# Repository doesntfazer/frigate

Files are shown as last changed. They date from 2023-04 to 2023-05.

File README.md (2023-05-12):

# frigate
32/34 Key Keyboard, integrated rp2040

# Frigate V1 is not working. V2 is the final version of this keyboard.
Frigate V2 final are not the same as the Early adopter boards. This one has all of the silscreens, and it is also wired to support i2c and SPI versions of the cirque.
The early adopters version only supports SPI.

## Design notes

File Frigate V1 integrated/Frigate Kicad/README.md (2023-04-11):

# frigate
32 Key Keyboard, integrated rp2040 With Hot Swap sockets

Order at your own risk. Keyboards have not yet been tested. (They have been ordered, and will be tested as soon as I get them)

frigate

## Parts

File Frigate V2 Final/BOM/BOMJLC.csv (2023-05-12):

Comment | Designator | Footprint | LCSC Part #
1N4148W | D1, D2, D3, D4, D5, D6, D7, D8, D9, D10, D11, D12, D13, D14, D15, D16, D17, D18, D19, D20, D21, D22, D23, D24, D25, D26, D27, D28, D29, D30, D31, D32, D33, D34 | D_SOD-123 | C25133
75 0402 | R1 | R_0402_1005Metric | C25798
LED_0603 | U2 | LED_0603 | C2286
SW_PUSH | SW1, SW2, SW3, SW4, SW5, SW6, SW7, SW8, SW9, SW10, SW11, SW12, SW13, SW14, SW15, SW16, SW17, SW18, SW19, SW20, SW21, SW22, SW23, SW24, SW25, SW26, SW27, SW28, SW29, SW30, SW31, SW32, SW33, SW34 | Kailh_socket_MX_4fab | C5156480

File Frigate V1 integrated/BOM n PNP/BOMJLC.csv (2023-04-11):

Comment | Designator | Footprint | LCSC Part #
10uf 0402 | C1, C2, C17 | C_0402_1005Metric | no_part_number
0.1uf 0402 | C3 | C_0402_1005Metric | no_part_number
100nf 0402 | C4, C5, C6, C7, C8, C9, C10, C11, C12, C15 | C_0402_1005Metric | no_part_number
2.2uF 0402 | C13, C16 | C_0402_1005Metric | no_part_number
1uf 0402 | C14 | C_0402_1005Metric | no_part_number
22pf 0402 | C18, C19 | C_0402_1005Metric | no_part_number
1N4148W | D1, D2, D3, D4, D5, D6, D7, D8, D9, D10, D11, D12, D13, D14, D15, D16, D17, D18, D19, D20, D21, D22, D23, D24, D25, D26, D27, D28, D29, D30, D31, D32 | D_SOD-123 | C2892570
1N4002W | D33 | D_SOD-123 | C169542
0805L050WR | F1 | Fuse_0805_2012Metric | C207022
FerriteBead 0402 | FB1 | R_0402_1005Metric | no_part_number
W25Q16JVUXIQ | FLASH1 | R_0402_1005Metric | C2843335
GP23 LED_0402 | GP23_LED1 | LED_0402_1005Metric | no_part_number
1K 0402 | GPIO24_RESISTOR1 | R_0402_1005Metric | no_part_number
LED_0402 | GPIO25_LED1 | LED_0402_1005Metric | no_part_number
470 0402 | GPIO25_RESISTOR1 | R_0402_1005Metric | no_part_number
Button | J3 | SW_Push_SPST_NO_Alps_SKRK | no_part_number
NetTie_2 | NT1 | NetTie-2_SMD_Pad0.5mm | no_part_number
SI2301B | Q1 | SOT-23 | no_part_number
5.1K 0402 | R1, R3 | R_0402_1005Metric | no_part_number
5.6K 0402 | R2 | R_0402_1005Metric | no_part_number
100K 0402 | R4 | R_0402_1005Metric | no_part_number
220 0402 | R5 | R_0402_1005Metric | no_part_number
10K 0402 | R6, R9 | R_0402_1005Metric | no_part_number
200 0603 | R7 | R_0402_1005Metric | no_part_number
1 0402 | R8 | R_0402_1005Metric | no_part_number
27r 0402 resistor | R10, R11 | R_0402_1005Metric | no_part_number
1K 0402 | R12, R13 | R_0402_1005Metric | no_part_number
TSA343G00-250J2 | RSW1 | SW_Push_SPST_NO_Alps_SKRK | C354946
SW_PUSH | SW1-SW32 | CherryMX_Hotswap-3d-smd | C5156480
TestPoint | TP1, TP2, TP3 | CustomTestPoint | no_part_number
SOT-23-5 5.5V 3.3V 500mA | U2 | SOT-23-5 | C404027
RP2040 | U3 | RP2040-QFN-56 | C2040
TYPE-C-31-M-12 | USB1 | HRO-TYPE-C-31-M-12 | C165948
3225_4P 12MHz | Y1 | Crystal_SMD_3225-4Pin_3.2x2.5mm | C295522

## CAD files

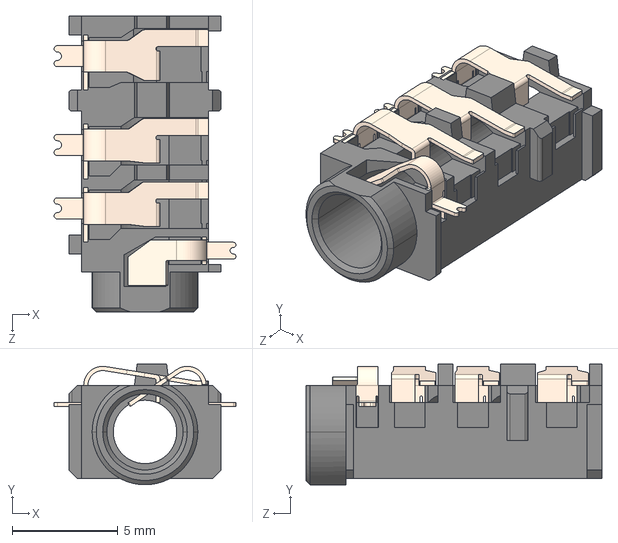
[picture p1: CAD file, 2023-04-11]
Frigate V1 integrated/components/Keebio-Parts.pretty-master/3dmodels/CUI_SJ-43614-SMT-TR.step
8.60 x 5.70 x 14.0 mm

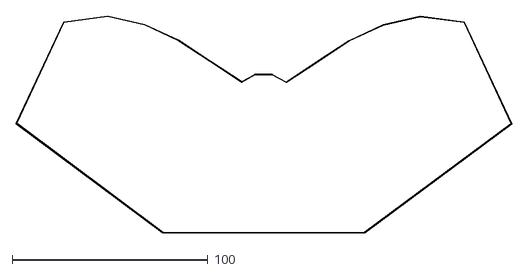
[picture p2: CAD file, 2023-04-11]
Frigate V1 integrated/DXF/32kb-Edge_Cuts.dxf
253.0 x 110.7

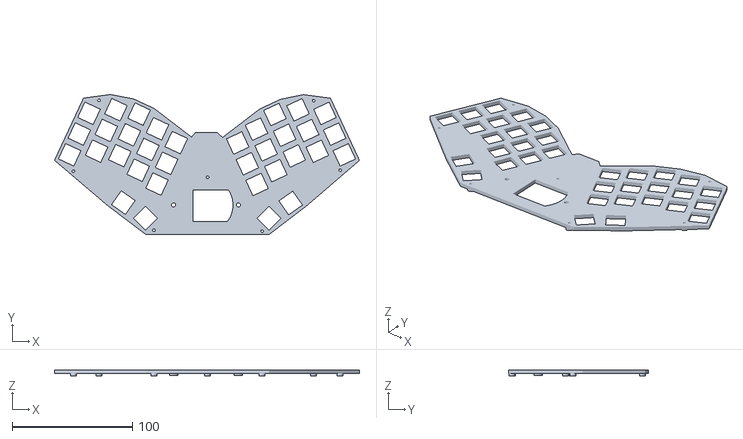
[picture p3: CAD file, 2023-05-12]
Frigate V2 Final/Case STL/Plate-4-Cirque.stl
254.0 x 116.6 x 5.00

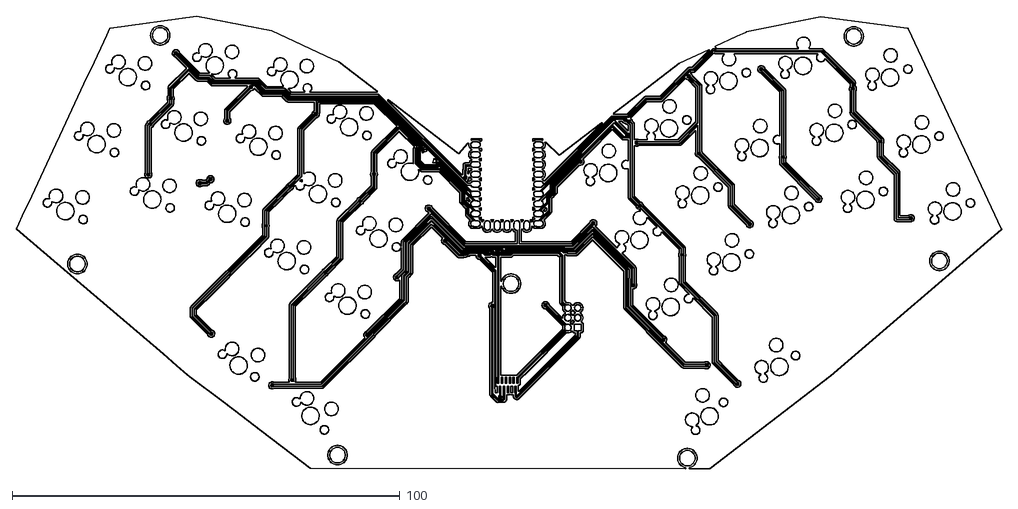
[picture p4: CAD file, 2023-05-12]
Frigate V2 Final/DXF/Frigate-F_Cu.dxf
253.9 x 116.6

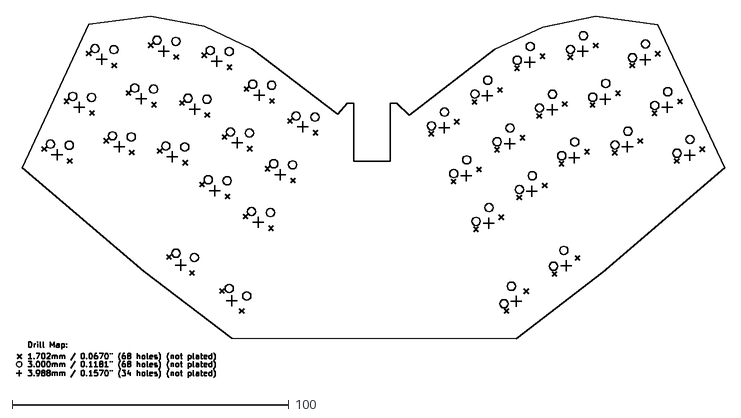
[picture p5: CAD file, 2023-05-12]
Frigate V2 Final/gerber/Frigate-NPTH-drl_map.dxf
256.1 x 130.8

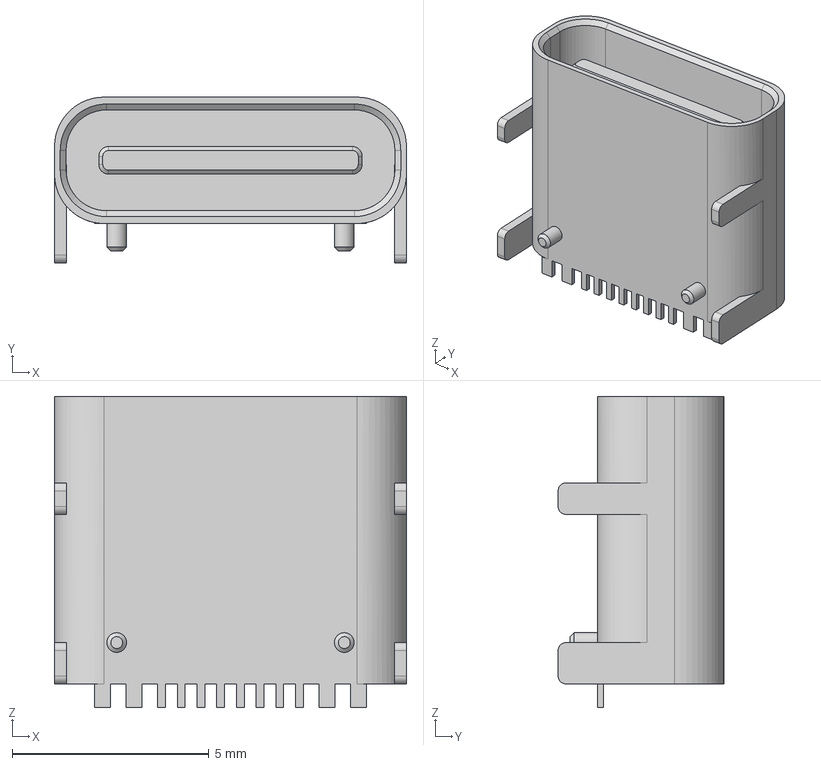
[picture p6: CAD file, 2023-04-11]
Frigate V1 integrated/components/Keebio-Parts.pretty-master/3dmodels/HRO TYPE-C-31-M-12.step
8.94 x 4.21 x 7.90 mm

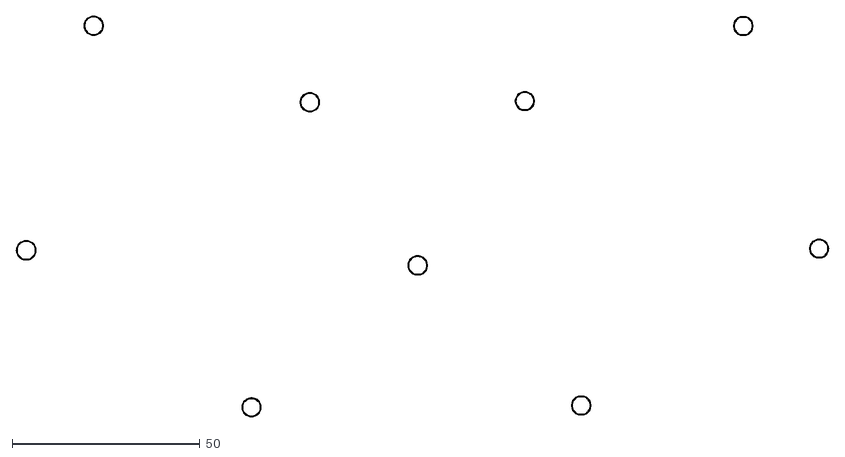
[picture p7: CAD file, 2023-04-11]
Frigate V1 integrated/DXF/32kb-User_3.dxf
216.5 x 106.8

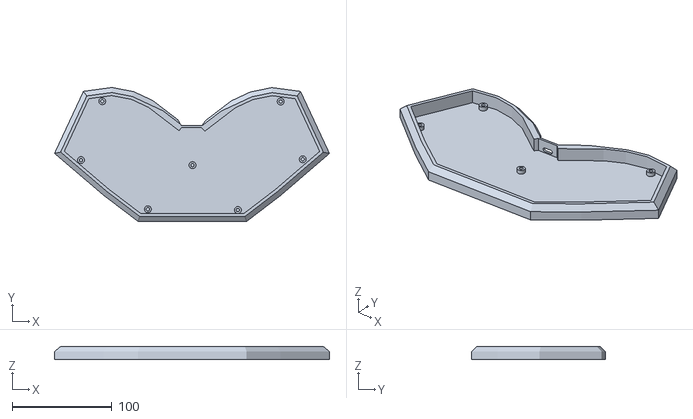
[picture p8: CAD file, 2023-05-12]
Frigate V2 Final/Case STL/Case-Thinnestbottom-fixed.stl
275.6 x 134.3 x 13.0

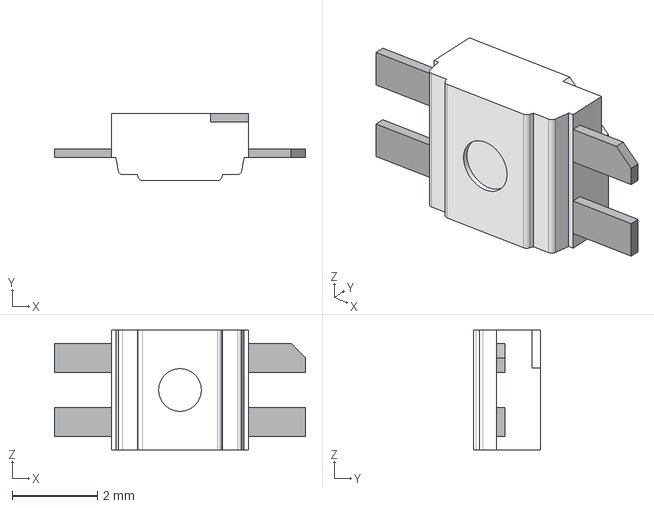
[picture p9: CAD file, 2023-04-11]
Frigate V2 Final/components/Keebio-Parts.pretty-master/3dmodels/SK6812MINI-E v1.step
5.88 x 1.58 x 2.80 mm

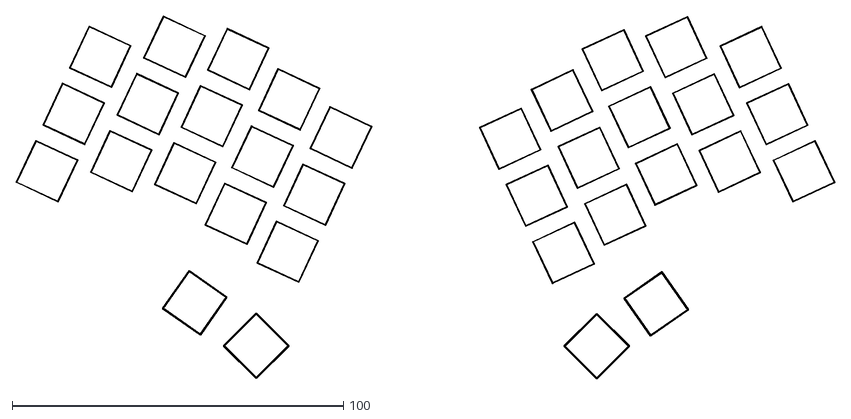
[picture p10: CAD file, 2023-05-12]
Frigate V2 Final/DXF/Frigate-User_Eco2.dxf
247.2 x 109.5

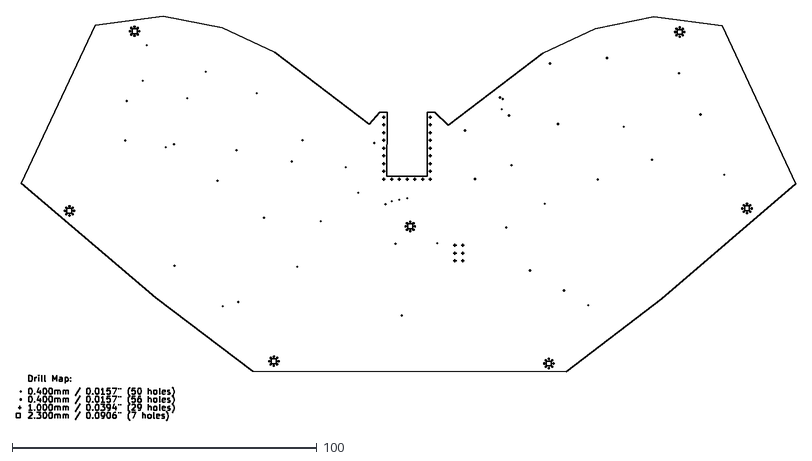
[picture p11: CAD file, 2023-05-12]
Frigate V2 Final/gerber/Frigate-PTH-drl_map.dxf
255.8 x 132.6

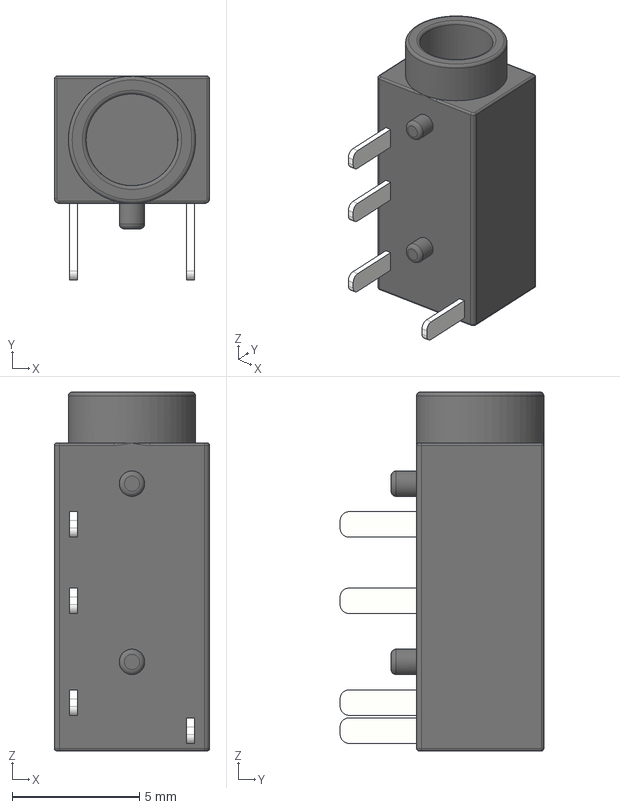
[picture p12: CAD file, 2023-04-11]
Frigate V1 integrated/components/Keebio-Parts.pretty-master/3dmodels/PJ-320A.step
6.10 x 8.00 x 14.1 mm

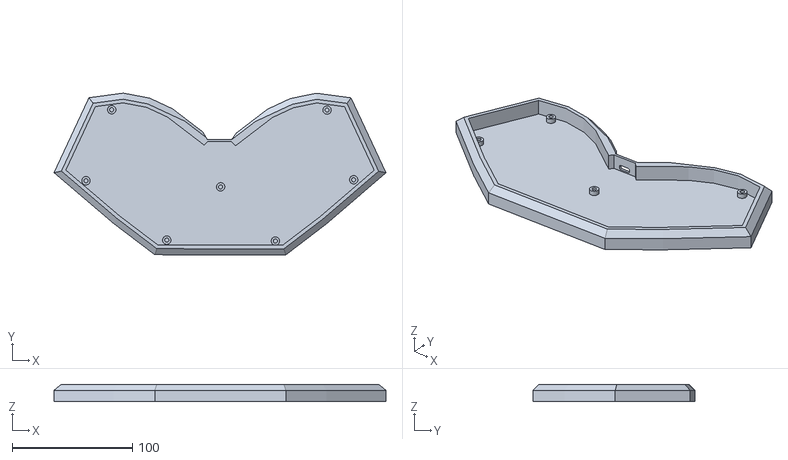
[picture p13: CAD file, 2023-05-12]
Frigate V2 Final/Case STL/Frigate-case-usbport.stl
275.6 x 134.3 x 14.5

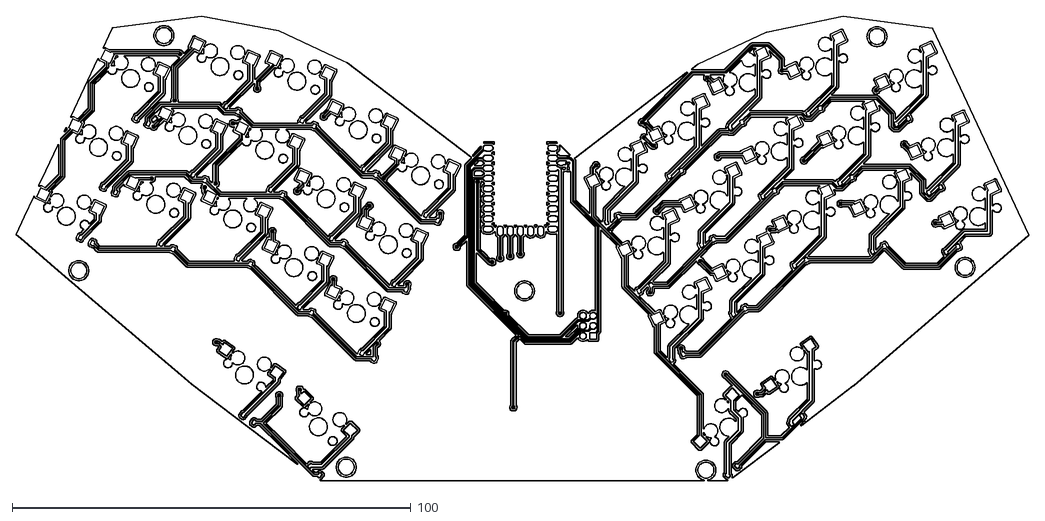
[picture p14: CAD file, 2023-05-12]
Frigate V2 Final/DXF/Frigate-B_Cu.dxf
253.9 x 116.6

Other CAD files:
Frigate V2 Final/Case STL/cirque case.stl
Frigate V1 integrated/components/KiCad-RP-Pico-main/SketchUp Model/Pico.skp
Frigate V2 Final/Case STL/Case.stl
Frigate V2 Final/Case STL/Cirque-trackpad-pretty.stl
Frigate V2 Final/Case STL/cirquecover.stl
Frigate V2 Final/Case STL/plate.stl
Frigate V2 Final/DXF/Frigate-B_Mask.dxf
Frigate V2 Final/DXF/Frigate-B_Paste.dxf
Frigate V2 Final/DXF/Frigate-B_Silkscreen.dxf
Frigate V2 Final/DXF/Frigate-Edge_Cuts.dxf
Frigate V2 Final/DXF/Frigate-F_Mask.dxf
Frigate V2 Final/DXF/Frigate-F_Paste.dxf
Frigate V2 Final/DXF/Frigate-F_Silkscreen.dxf
Frigate V2 Final/components/KiCad-RP-Pico-main/SketchUp Model/Pico.skp
Frigate V2 Final/components/Molex/0781271220.stp

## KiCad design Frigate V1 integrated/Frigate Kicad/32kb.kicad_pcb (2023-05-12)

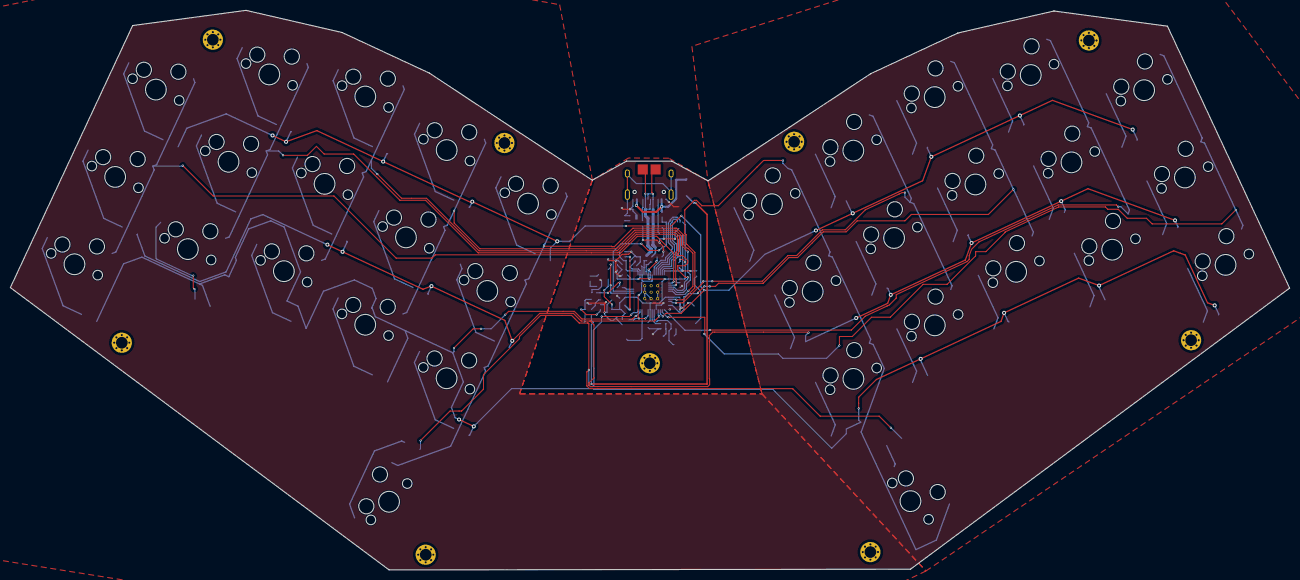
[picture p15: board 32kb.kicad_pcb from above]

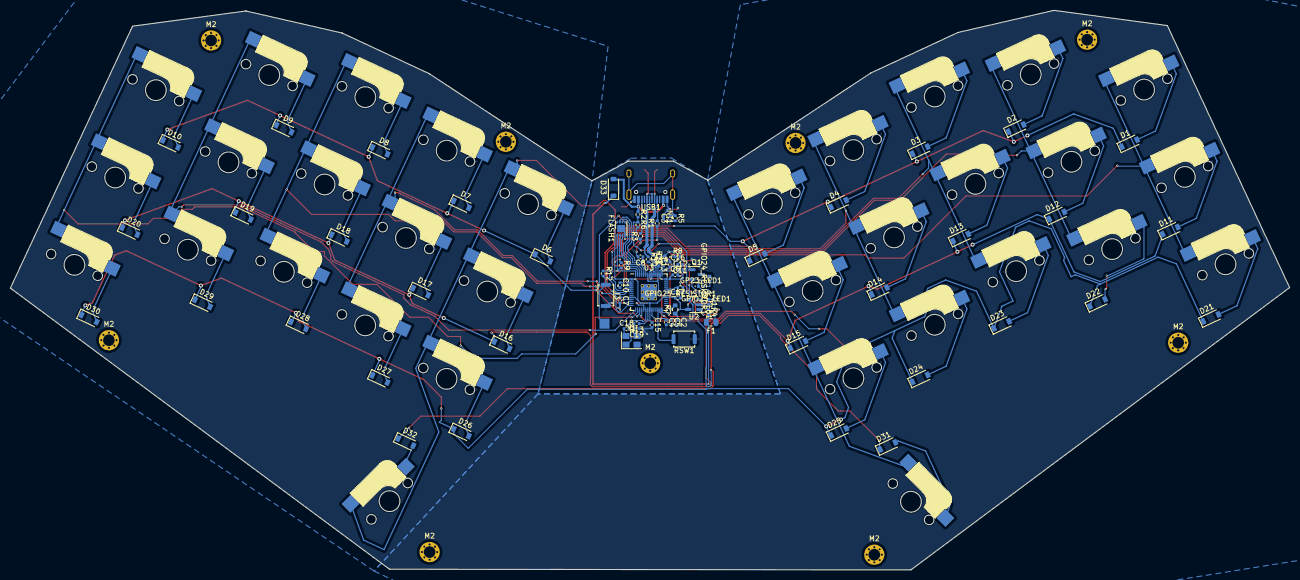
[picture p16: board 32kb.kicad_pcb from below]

Board: 2 copper layers, 252.9 x 110.6 mm, 124 parts (90 on the bottom side), 80 nets.

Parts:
C1, C2, C17: 10uf 0402; C_0402_1005Metric
C3: 0.1uf 0402; C_0402_1005Metric
C4, C5, C6, C7, C8, C9, C10, C11, C12, C15: 100nf 0402; C_0402_1005Metric
C13, C16: 2.2uF 0402; C_0402_1005Metric
C14: 1uf 0402; C_0402_1005Metric
C18, C19: 22pf 0402; C_0402_1005Metric
D1, D2, D3, D4, D5, D6, D7, D8, D9, D10, D11, D12, D13, D14, D15, D16, D17, D18, D19, D20, D21, D22, D23, D24, D25, D26, D27, D28, D29, D30, D31, D32: 1N4148W; D_SOD-123
D33: 1N4002W; D_SOD-123
F1: 0805L050WR; Fuse_0805_2012Metric
FB1: FerriteBead 0402; R_0402_1005Metric
FLASH1: W25Q16JVUXIQ; SON-8-1EP_3x2mm_P0.5mm_EP1.4x1.6mm
GP23_LED1: GP23 LED_0402; LED_0402_1005Metric
GPIO24_RESISTOR1: 1K 0402; R_0402_1005Metric
GPIO25_LED1: LED_0402; LED_0402_1005Metric
GPIO25_RESISTOR1: 470 0402; R_0402_1005Metric
J3: Button; SW_Push_SPST_NO_Alps_SKRK
M2, M2#2, M2#3, M2#4, M2#5, M2#6, M2#7, M2#8, M2#9: M2; M2_HOLE_v3
NT1: NetTie_2; NetTie-2_SMD_Pad0.5mm
Q1: SI2301B; SOT-23
R1, R3: 5.1K 0402; R_0402_1005Metric
R2: 5.6K 0402; R_0402_1005Metric
R4: 100K 0402; R_0402_1005Metric
R5: 220 0402; R_0402_1005Metric
R6, R9: 10K 0402; R_0402_1005Metric
R7: 200 0603; R_0603_1608Metric
R8: 1 0402; R_0402_1005Metric
R10, R11: 27r 0402 resistor; R_0402_1005Metric
R12, R13: 1K 0402; R_0402_1005Metric
RSW1: TSA343G00-250J2; SW_Push_SPST_NO_Alps_SKRK
SW1, SW2, SW3, SW4, SW5, SW6, SW7, SW8, SW9, SW10, SW11, SW12, SW13, SW14, SW15, SW16, SW17, SW18, SW19, SW20, SW21, SW22, SW23, SW24, SW25, SW26, SW27, SW28, SW29, SW30, SW31, SW32: SW_PUSH; CherryMX_Hotswap-3d-smd
TP1, TP2, TP3: TestPoint; CustomTestPoint
U2: SOT-23-5 5.5V 3.3V 500mA; SOT-23-5
U3: RP2040; RP2040-QFN-56
USB1: TYPE-C-31-M-12; HRO-TYPE-C-31-M-12
Y1: 3225_4P 12MHz; Crystal_SMD_3225-4Pin_3.2x2.5mm

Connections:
3V3_EN: R4.1, U2.3 (EN)
+1V1: C4.1, C5.1, C14.1, U3.23 (DVDD), U3.45 (VREG_VOUT), U3.50 (DVDD)
+3V3: C2.1, C6.1, C7.1, C8.1, C9.1, C10.1, C11.1, C12.1, C13.1, C15.1, C17.1, FLASH1.8 (VCC), Q1.2 (S), R7.1, R9.1, U2.5 (OUT), U3.1 (IOVDD), U3.10 (IOVDD), U3.22 (IOVDD), U3.33 (IOVDD), U3.42 (IOVDD), U3.44 (VREG_IN), U3.48 (USB_VDD), U3.49 (IOVDD)
/rp2040/ADC_VREF: R7.2, R8.1
/rp2040/GPIO23: Q1.1 (G), U3.35 (GPIO23)
/rp2040/GPIO24: R2.2, R6.1, U3.36 (GPIO24)
/rp2040/GPIO25: GPIO25_RESISTOR1.2, U3.37 (GPIO25)
/rp2040/QSPI_SCLK: FLASH1.6 (CLK), U3.52 (QSPI_SCLK)
/rp2040/QSPI_SD0: FLASH1.5 (DI(IO0)), U3.53 (QSPI_SD0)
/rp2040/QSPI_SD1: FLASH1.2 (DO(IO1)), U3.55 (QSPI_SD1)
/rp2040/QSPI_SD2: FLASH1.3 (IO2), U3.54 (QSPI_SD2)
/rp2040/QSPI_SD3: FLASH1.7 (IO3), U3.51 (QSPI_SD3)
/rp2040/QSPI_SS: FLASH1.1 (~CS), R9.2, R12.1, U3.56 (QSPI_SS)
/rp2040/RUN: RSW1.2, U3.26 (RUN)
/rp2040/~USB_BOOT: J3.1, R12.2, TP3.1
COL0: SW1.2, SW11.2, SW21.2, U3.3 (GPIO1)
COL1: SW2.2, SW12.2, SW22.2, U3.4 (GPIO2)
COL2: SW3.2, SW13.2, SW23.2, U3.5 (GPIO3)
COL3: SW4.2, SW14.2, SW24.2, U3.6 (GPIO4)
COL4: SW5.2, SW15.2, SW25.2, SW31.2, U3.7 (GPIO5)
COL5: SW6.2, SW16.2, SW26.2, SW32.2, U3.11 (GPIO8)
COL6: SW7.2, SW17.2, SW27.2, U3.12 (GPIO9)
COL7: SW8.2, SW18.2, SW28.2, U3.14 (GPIO11)
COL8: SW9.2, SW19.2, SW29.2, U3.15 (GPIO12)
COL9: SW10.2, SW20.2, SW30.2, U3.16 (GPIO13)
GND: C1.2, C2.2, C3.1, C4.2, C5.2, C6.2, C7.2, C8.2, C9.2, C10.2, C11.2, C12.2, C13.2, C14.2, C15.2, C16.2, C17.2, C18.1, C19.1, FLASH1.4 (GND), FLASH1.9 (EP), GP23_LED1.1 (K), GPIO25_LED1.1 (K), J3.2, NT1.1, R1.1, R3.1, R5.2, R6.2, RSW1.1, U2.2 (GND), U2.4 (BP), U3.19 (TESTEN), U3.57 (GND), USB1.1 (GND), USB1.12 (GND), Y1.2, Y1.4
unnamed: C19.2, R13.2, Y1.3
unnamed: D1.2 (A), SW1.1
unnamed: D2.2 (A), SW2.1
unnamed: D3.2 (A), SW3.1
unnamed: D4.2 (A), SW4.1
unnamed: D5.2 (A), SW5.1
unnamed: D6.2 (A), SW6.1
unnamed: D7.2 (A), SW7.1
unnamed: D8.2 (A), SW8.1
unnamed: D9.2 (A), SW9.1
unnamed: D10.2 (A), SW10.1
unnamed: D11.2 (A), SW11.1
unnamed: D12.2 (A), SW12.1
unnamed: D13.2 (A), SW13.1
unnamed: D14.2 (A), SW14.1
unnamed: D15.2 (A), SW15.1
unnamed: D16.2 (A), SW16.1
unnamed: D17.2 (A), SW17.1
unnamed: D18.2 (A), SW18.1
unnamed: D19.2 (A), SW19.1
unnamed: D20.2 (A), SW20.1
unnamed: D21.2 (A), SW21.1
unnamed: D22.2 (A), SW22.1
unnamed: D23.2 (A), SW23.1
unnamed: D24.2 (A), SW24.1
unnamed: D25.2 (A), SW25.1
unnamed: D26.2 (A), SW26.1
unnamed: D27.2 (A), SW27.1
unnamed: D28.2 (A), SW28.1
unnamed: D29.2 (A), SW29.1
unnamed: D30.2 (A), SW30.1
unnamed: D31.2 (A), SW31.1
unnamed: D32.2 (A), SW32.1
unnamed: F1.1, FB1.1
unnamed: GP23_LED1.2 (A), GPIO24_RESISTOR1.1
unnamed: GPIO25_LED1.2 (A), GPIO25_RESISTOR1.1
unnamed: GPIO24_RESISTOR1.2, Q1.3 (D)
unnamed: C1.1, FB1.2, U2.1 (IN)
unnamed: C16.1, R8.2, U3.43 (ADC_AVDD)
unnamed: R11.2, U3.46 (USB_DM)
unnamed: R10.2, U3.47 (USB_DP)
unnamed: R1.2, USB1.4 (CC1)
unnamed: R3.2, USB1.10 (CC2)
unnamed: C3.2, R5.1, USB1.13 (SHIELD)
ROW0: D1.1 (K), D2.1 (K), D3.1 (K), D4.1 (K), D5.1 (K), D6.1 (K), D7.1 (K), D8.1 (K), D9.1 (K), D10.1 (K), U3.17 (GPIO14)
ROW1: D11.1 (K), D12.1 (K), D13.1 (K), D14.1 (K), D15.1 (K), D16.1 (K), D17.1 (K), D18.1 (K), D19.1 (K), D20.1 (K), U3.18 (GPIO15)
ROW2: D21.1 (K), D22.1 (K), D23.1 (K), D24.1 (K), D25.1 (K), D26.1 (K), D27.1 (K), D28.1 (K), D29.1 (K), D30.1 (K), U3.27 (GPIO16)
ROW3: D31.1 (K), D32.1 (K), U3.28 (GPIO17)
USB_D+: R10.1, TP1.1, USB1.6 (DP1), USB1.8 (DP2)
USB_D-: R11.1, TP2.1, USB1.5 (DN2), USB1.7 (DN1)
VBUS: D33.2 (A), R2.1, USB1.2 (VBUS), USB1.11 (VBUS)
VSYS: D33.1 (K), F1.2, R4.2
XIN: C18.2, U3.20 (XIN), Y1.1
XOUT: R13.1, U3.21 (XOUT)

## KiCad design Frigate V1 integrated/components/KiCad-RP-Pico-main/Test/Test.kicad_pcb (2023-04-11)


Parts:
J1, J2: Conn_01x20; PinSocket_1x20_P1.00mm_Vertical
J3: Conn_01x03; PinSocket_1x03_P1.00mm_Vertical
U1: Pico; RPi_Pico_SMD_TH

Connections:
GND: J1.3, J1.8, J1.13, J1.18, J2.3, J2.13, J2.18, J3.2, U1.3 (GND), U1.8 (GND), U1.13 (GND), U1.18 (GND), U1.23 (GND), U1.28 (GND), U1.38 (GND), U1.42 (GND)
unnamed: J1.1, U1.1 (GPIO0)
unnamed: J1.2, U1.2 (GPIO1)
unnamed: J1.4, U1.4 (GPIO2)
unnamed: J1.5, U1.5 (GPIO3)
unnamed: J1.6, U1.6 (GPIO4)
unnamed: J1.7, U1.7 (GPIO5)
unnamed: J1.9, U1.9 (GPIO6)
unnamed: J1.10, U1.10 (GPIO7)
unnamed: J1.11, U1.11 (GPIO8)
unnamed: J1.12, U1.12 (GPIO9)
unnamed: J1.14, U1.14 (GPIO10)
unnamed: J1.15, U1.15 (GPIO11)
unnamed: J1.16, U1.16 (GPIO12)
unnamed: J1.17, U1.17 (GPIO13)
unnamed: J1.19, U1.19 (GPIO14)
unnamed: J1.20, U1.20 (GPIO15)
unnamed: J2.1, U1.40 (VBUS)
unnamed: J2.2, U1.39 (VSYS)
unnamed: J2.4, U1.37 (3V3_EN)
unnamed: J2.5, U1.36 (3V3)
unnamed: J2.6, U1.35 (ADC_VREF)
unnamed: J2.7, U1.34 (GPIO28_ADC2)
unnamed: J2.8, U1.33 (AGND)
unnamed: J2.9, U1.32 (GPIO27_ADC1)
unnamed: J2.10, U1.31 (GPIO26_ADC0)
unnamed: J2.11, U1.30 (RUN)
unnamed: J2.12, U1.29 (GPIO22)
unnamed: J2.14, U1.27 (GPIO21)
unnamed: J2.15, U1.26 (GPIO20)
unnamed: J2.16, U1.25 (GPIO19)
unnamed: J2.17, U1.24 (GPIO18)
unnamed: J2.19, U1.22 (GPIO17)
unnamed: J2.20, U1.21 (GPIO16)
unnamed: J3.1, U1.43 (SWDIO)
unnamed: J3.3, U1.41 (SWCLK)


Board: 2 copper layers, 43.0 x 65.0 mm, 4 parts (0 on the bottom side), 36 nets.

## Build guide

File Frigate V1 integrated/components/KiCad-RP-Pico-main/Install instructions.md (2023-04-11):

# Install instructions

## 1. Copy the files locally

Copy the `RP-Pico Libraries` folder wherever you like on your computer.

## 2. Install the Raspberry Pi Pico board schema symbol

Use the `KiCad | Preferences | Manage Symbol Libraries...` command to manage the symbol library:



then select the global tab and click on the folder button:



navigate to the `RP-Pico Libraries` folder, select the `MCU_RaspberryPi_and_Boards.kicad_sym` file and open it:



et voilà, the first step is completed:



You can now close the symbol libraries manager window.

## 3. Install the Raspberry Pi Pico board footprint

You can use a similar approach to add the footprint to the footprint libraries manager, but I've found some issues that I've solved using the footprint editor, so here are the steps I suggest you to follow:

Open the footprint editor



wait for the footprints to load... then use the `File | Add Library` command:



confirm the `Global` choice:



and select the `MCU_RaspberriPi_and_Boards.pretty` folder (yes, the folder represent a footprint library on KiCad):



Now the library is installed on KiCad with the Raspberry Pi Pico footprint (double click on it to see it on the editor pane):



Don't close the windows as the next step start from here.

## 4. Install the Raspberry Pi Pico board footprint 3D visual

If not already open, open the the footprint editor

symbol library manager

double click on the `RPi_Pico_SMD_TH` footprint from the `MCU_RaspberriPi_and_Boards` library and then click on the `Footprint properties` icon:



In the footprint properties window, first select the `3D Settings` tab. Please note that the preview shows only the PCB board with the footprint added on step 3, without any 3D representation of the Raspberry Pi Pico board. Now click on the folder icon to add the 3D model:



Navigate to the `RP-Pico Libraries` folder, select the `Pico.wrl` file and wait until the model is shown in the right panel, then confirm with OK:



The model is already scaled and translated to match the footprint:



now close the `Footprint Properties` window, and the `Footprint Editor`, obviously saving the changes.

## Conclusion

Now that you've installed the schema and footprint and added the 3D model to the footprint, you can use the Raspberry Pi Pico board on your KiCad projects.

I've also added a test KiCad Project on the `Test` folder, that you can use to see an example of it.

Have fun!

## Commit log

2023-05-12 Added V2 final renamed v1
    [0781271220.stp, 32kb.kicad_pcb, 32kb.kicad_sch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]
2023-05-12 Moving stuff around
    [0781271220.stp, 32kb-Edge_Cuts.dxf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]
